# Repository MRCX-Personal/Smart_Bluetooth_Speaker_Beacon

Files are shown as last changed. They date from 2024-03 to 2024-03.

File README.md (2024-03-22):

# Smart Speech Recognition Bluetooth Speaker and RGB Full Color light in the shape of the Beacon in game Minecraft

zh-CN/简体中文：[查看链接](https://) <br>

This project is a Smart Bluetooth Speaker in the shape of the Beacon in game Minecraft. <br>
This repository includes programs, circuit information, and 3D models of this project. <br>
The video demonstration and tutorial for this project:[Bilibili](https://www.bilibili.com/video/av1401504252/) <br>
I would greatly appreciate it if you press like or subscribe. <br>

## Features/功能
* Bluetooth speaker/蓝牙音箱
* voice recognize/voice commands/语音控制
* RGB Full Color Night light/Atmosphere light/RGB全彩氛围灯
* Build in Battery/内置电池，可离线使用
* Glow at dark environment/暗处有荧光效果（吸收光线以发光，不耗电）

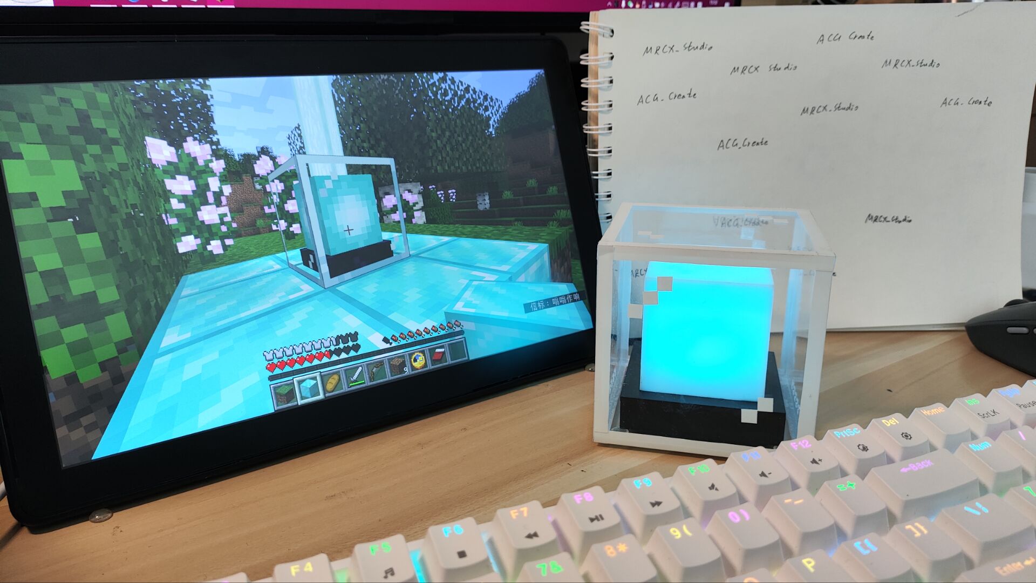
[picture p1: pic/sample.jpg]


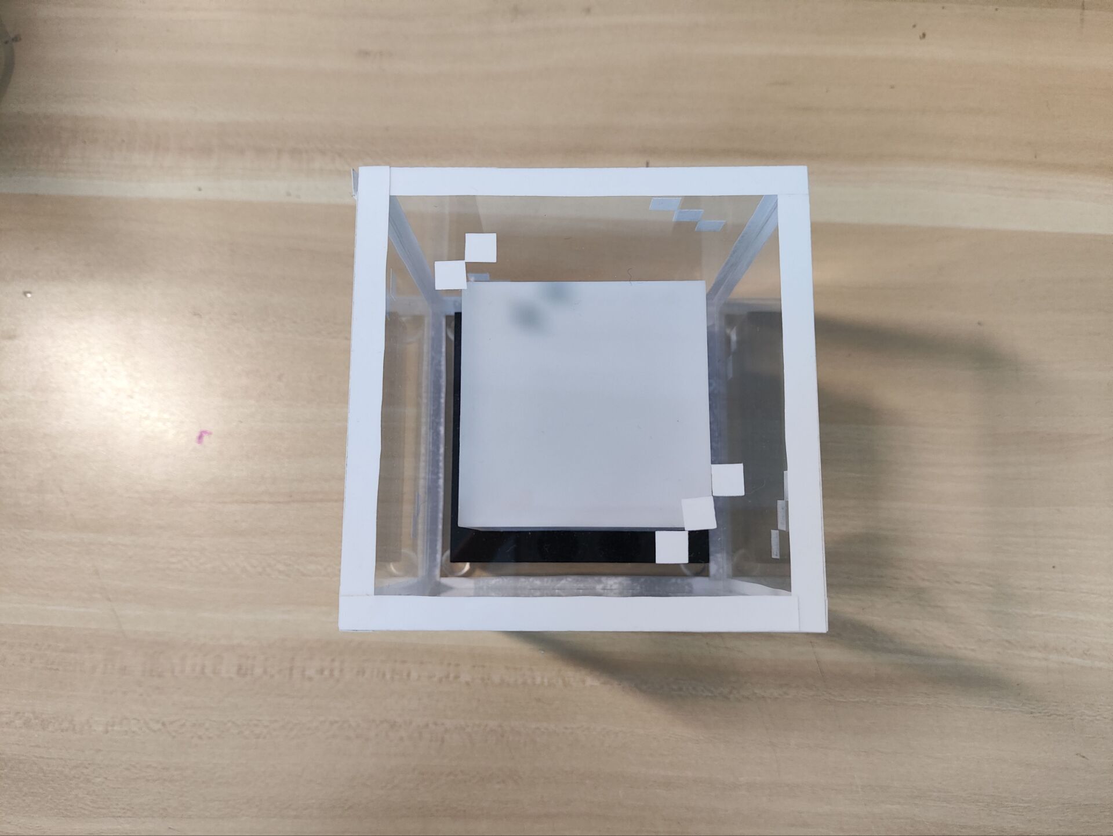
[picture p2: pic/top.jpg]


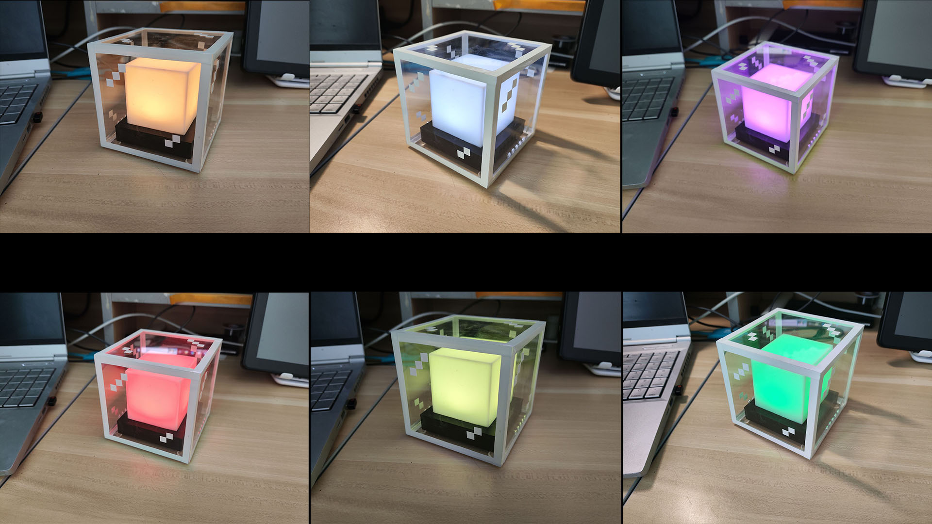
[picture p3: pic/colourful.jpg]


## Component List/原件清单
* WS2812/全彩LED灯珠
* asrpro/语音识别开发板，作为主控
* 3.7V battery/电池和3.7-5v充放电升压板
* speaker*2/2个扬声器，这里选用的是2个lg g7的拆机扬声器
* Bluetooth receiver/蓝牙音频接收板，这里选用的是“MH-M18”的板子，支持3.7v或者5v输入，有按键控制
* 音频功放板，如果使用的蓝牙板自带功放，则不需要此原件，这里选用的是PAM8403

## Circuit and connect/电路连接

```
Type-C:
DM-RXD-PB5
DP-TXD-PB6

WS2812:
VCC-5V
GND-GND
IN-PA6

BLE receiver:
key-PA3 
```
you can view this picture as reference.
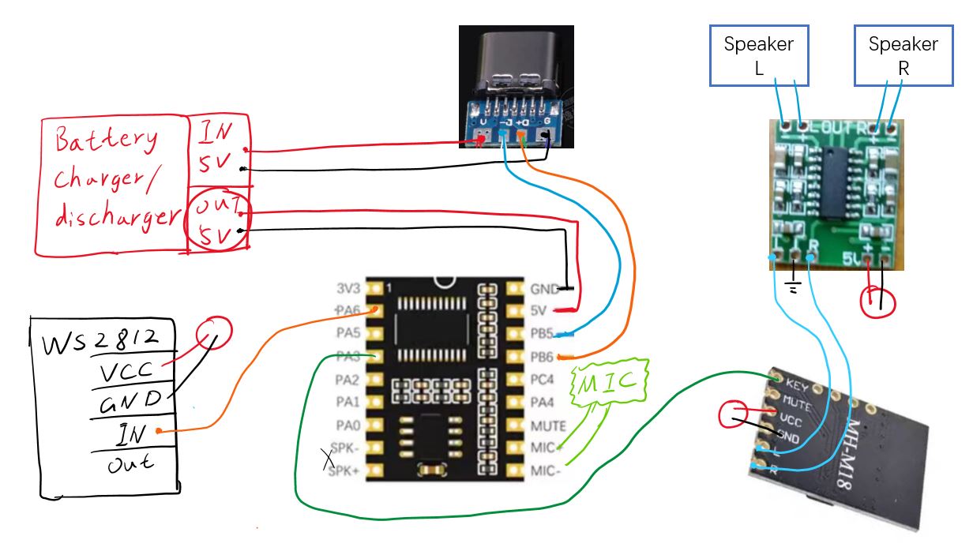
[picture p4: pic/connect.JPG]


## Reference documents/参考资料
* [ASRPRO扩展库[WS2812]](https://haohaodada.com/new/bbs/forum.php?mod=viewthread&tid=860&extra=)
* [ASRPRO 核心板规格书](http://www.haohaodada.com/jpeguploadfile/twen/ASRPRO/ASRPROCoreV1.1.pdf)

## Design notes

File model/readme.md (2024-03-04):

成品尺寸为90x90x90mm。如果使用仓库的图纸，请按照文件名来打样，以保证能拼成一个完好的正方体。

匀光碗尽量选用透光材料打印，也可也用亚克力制作，但难度较大。

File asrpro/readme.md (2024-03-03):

"asrpro.cpp" 和 "asrpro.hd"是未经编译的源代码，您可以使用"天问Block"来修改或者编译。（两者内容一样，.hd文件可以直接用天问Block打开，cpp需要新建纯代码工程然后导入。）项目使用了“newS2812.h”库，请自行前往天问Block的“扩展库中心”下载，感谢该库作者的劳动成果。<br>
"fw.bin"是已经编译好的固件，可以直接用天问Block附带的烧录软件和CH340进行烧录，无需再编译。<br>
<br>
"asrpro.cpp" and "asrpro.hd" are the program source code, you can use "天问Block" IDE to edit and build it.And "fw.bin" is the compiled firmware,you can directly flash it into asrpro use CH340.

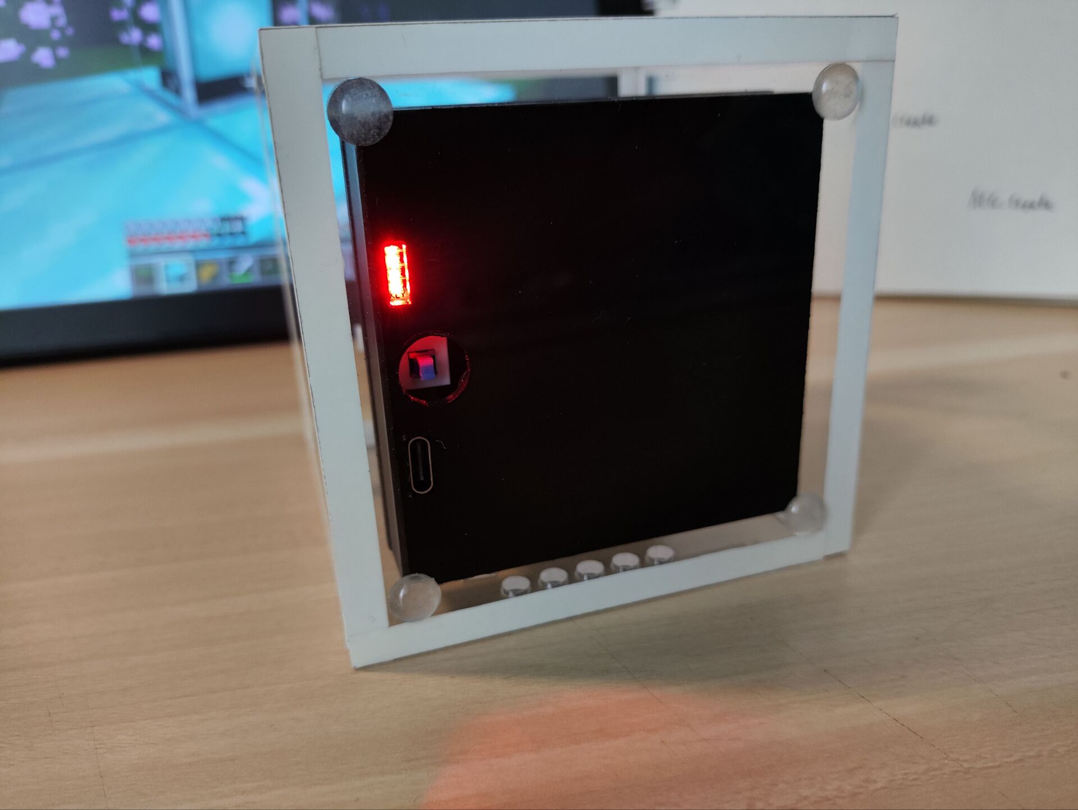
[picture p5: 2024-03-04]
pic/bottom.jpg

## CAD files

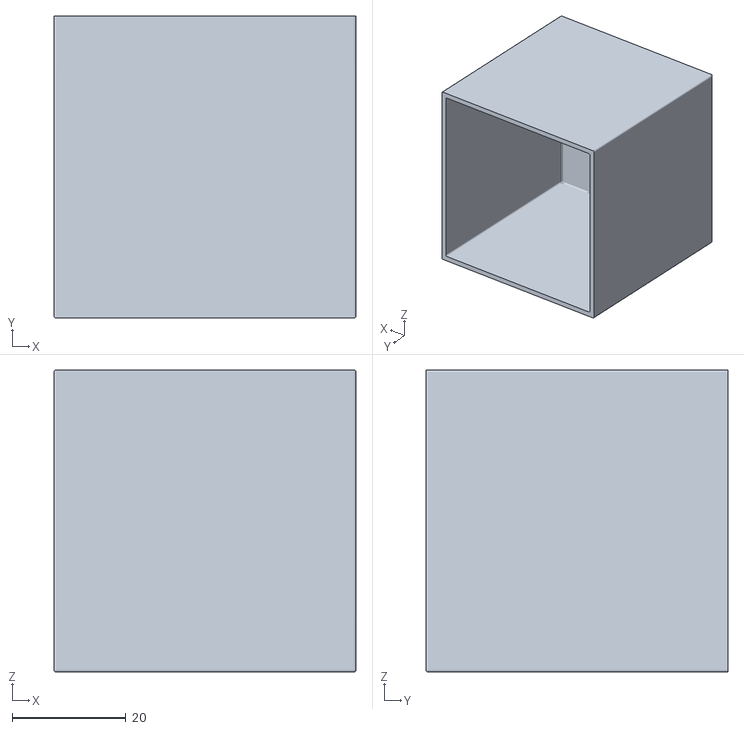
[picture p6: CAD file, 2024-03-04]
model/方块匀光碗-fin.STL
53.0 x 53.0 x 53.0

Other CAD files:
model/内-黑色3mm.dwg
model/涂层-透明1mm.dwg
model/外-透明3mm.dwg

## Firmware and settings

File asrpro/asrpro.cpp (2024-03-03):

#define N_PIXELS 1
#include "asr.h"
extern "C"{ void * __dso_handle = 0 ;}
#include "setup.h"
#include "newS2812.h"
//by ACG_Create 渺若尘兮

uint32_t snid;
WS2812 ws2812 = WS2812(6,1,255);//初始化（1）个ws2812在PA_6端口
uint8_t rainbows = 1;
uint8_t var;

void rainbow(){
	randomSeed(millis());
	while(rainbows == 1){
	  ws2812.rainbowCycle(10);//修改这个函数调用以修改ID91效果

	}
	ws2812.clear();
	vTaskDelete(NULL);
}

  void welcome(){
  ws2812.pixel_set_all_color(255,0,0);
  ws2812.pixel_show();
  delay(300);
  ws2812.pixel_set_all_color(0,255,0);
  ws2812.pixel_show();
  delay(300);
  ws2812.pixel_set_all_color(0,0,255);
  ws2812.pixel_show();
  delay(300);
  ws2812.pixel_set_all_color(0,0,0);
  ws2812.pixel_show();
    //上电欢迎，RGB闪一次 
  }

void ASR_CODE();

//{speak:小蝶-清新女声,vol:10,speed:10,platform:haohaodada}
//{playid:10001,voice:}
//10001欢迎语音
//{playid:10002,voice:}
//10002退出语音

void ASR_CODE(){
    set_state_enter_wakeup(120000);
    
    
 
    
  //case后面的是语音识别的ID 
  switch (snid) {

    case 0:
        ws2812.pixel_set_all_color(255,255,255);
        ws2812.pixel_show();
        delay(300);
        ws2812.pixel_set_all_color(0,0,0);
        ws2812.pixel_show();
        delay(300);
        ws2812.pixel_set_all_color(255,255,255);
        ws2812.pixel_show();
        delay(300);
        ws2812.pixel_set_all_color(0,0,0);
        ws2812.pixel_show();
    break;



    case 11:
        ws2812.pixel_set_all_color(0,255,255);
        ws2812.pixel_show();
    break;

    case 10:
        rainbows = 0;
        ws2812.pixel_set_all_color(0,0,0);
        ws2812.pixel_show();       
    break;

    case 12:
        ws2812.setBrightness(254);
        ws2812.pixel_show(); 
    break;

    case 13:
        ws2812.setBrightness(100);
        ws2812.pixel_show();         
    break;


    case 14:
        while(1 == 1){
            for (int a=0; a<=255;a++){
                ws2812.setBrightness(a);
                ws2812.pixel_show();
                delay(8);
            }
             for (int a=255; a>=0;a--){
                ws2812.setBrightness(a);
                ws2812.pixel_show();
                delay(8);
            }
        }
    break;

    case 21:
      digitalWrite(3,1);
      ws2812.pixel_set_all_color(255,0,0);
      ws2812.pixel_show();
      delay(400);
      ws2812.pixel_set_all_color(0,0,255);
      ws2812.pixel_show();
      delay(800);
      ws2812.pixel_set_all_color(0,0,0);
      ws2812.pixel_show();
    break;
    case 20:
      digitalWrite(3,0);
      ws2812.pixel_set_all_color(0,0,255);
      ws2812.pixel_show();
      delay(400);
      ws2812.pixel_set_all_color(255,0,0);
      ws2812.pixel_show();
      delay(800);
      ws2812.pixel_set_all_color(0,0,0);
      ws2812.pixel_show();
    break;

    case 31:
      ws2812.pixel_set_all_color(255,0,0);
      ws2812.pixel_show();
    break;

    case 32:
      ws2812.pixel_set_all_color(0,255,0);
      ws2812.pixel_show();    
    break;

    case 33:
      ws2812.pixel_set_all_color(0,0,255);
      ws2812.pixel_show();    
    break;

    case 34:
      //int rr = random(50,255);
      //int rg = random(50,255);
      //int rb = random(50,255);
      ws2812.pixel_set_all_color(random(0,255),random(0,255),random(0,255));
      ws2812.pixel_show(); 
    break;

    case 36:
      ws2812.pixel_set_all_color(0,255,255);
      ws2812.pixel_show();    
    break;

    case 37:
      ws2812.pixel_set_all_color(255,0,255);
      ws2812.pixel_show();    
    break;

    case 38:
      ws2812.pixel_set_all_color(255,100,0);
      ws2812.pixel_show();    
    break;

    case 39:
      ws2812.pixel_set_all_color(255,255,0);
      ws2812.pixel_show();    
    break;

    case 310:
      ws2812.pixel_set_all_color(255,255,255);
      ws2812.pixel_show();
    break;

    case 91:
      rainbows = 1;
      xTaskCreate(rainbow,"rainbow",128,NULL,4,NULL);
    break;

    case 90:
      rainbows = 0;
    break;

  }

}

void hardware_init(){
  vol_set(1);
  setPinFun(3,FIRST_FUNCTION);
  pinMode(3,output);
  //PA_3设置为输出,PA3接蓝牙板的VCC，蓝牙板和asr共地
  digitalWrite(3,0);//上电默认蓝牙为关
  vTaskDelete(NULL);
  welcome();
}

void setup()
{ 
  //{ID:0,keyword:"唤醒词",ASR:"蓝牙信标",ASRTO:"我在"}

  //{ID:11,keyword:"命令词",ASR:"打开灯光",ASRTO:"好的"}
  //{ID:10,keyword:"命令词",ASR:"关闭灯光",ASRTO:"好的"}
  //{ID:21,keyword:"命令词",ASR:"打开蓝牙",ASRTO:"好的"}
  //{ID:20,keyword:"命令词",ASR:"关闭蓝牙",ASRTO:"好的"}
  //{ID:12,keyword:"命令词",ASR:"高亮度",ASRTO:"好的"}
  //{ID:13,keyword:"命令词",ASR:"低亮度",ASRTO:"好的"}

  //{ID:31,keyword:"命令词",ASR:"红色",ASRTO:"好的"}
  //{ID:32,keyword:"命令词",ASR:"绿色",ASRTO:"好的"}
  //{ID:33,keyword:"命令词",ASR:"蓝色",ASRTO:"好的"}
  //{ID:36,keyword:"命令词",ASR:"青色",ASRTO:"好的"}
  //{ID:37,keyword:"命令词",ASR:"紫色",ASRTO:"好的"}
  //{ID:38,keyword:"命令词",ASR:"橙色",ASRTO:"好的"}
  //{ID:39,keyword:"命令词",ASR:"黄色",ASRTO:"好的"}
  //{ID:310,keyword:"命令词",ASR:"白色",ASRTO:"好的"}
  //{ID:34,keyword:"命令词",ASR:"随机颜色",ASRTO:"好的"}

  //{ID:91,keyword:"命令词",ASR:"打开彩灯",ASRTO:"好的"}
  //{ID:90,keyword:"命令词",ASR:"关闭彩灯",ASRTO:"好的"}
}
